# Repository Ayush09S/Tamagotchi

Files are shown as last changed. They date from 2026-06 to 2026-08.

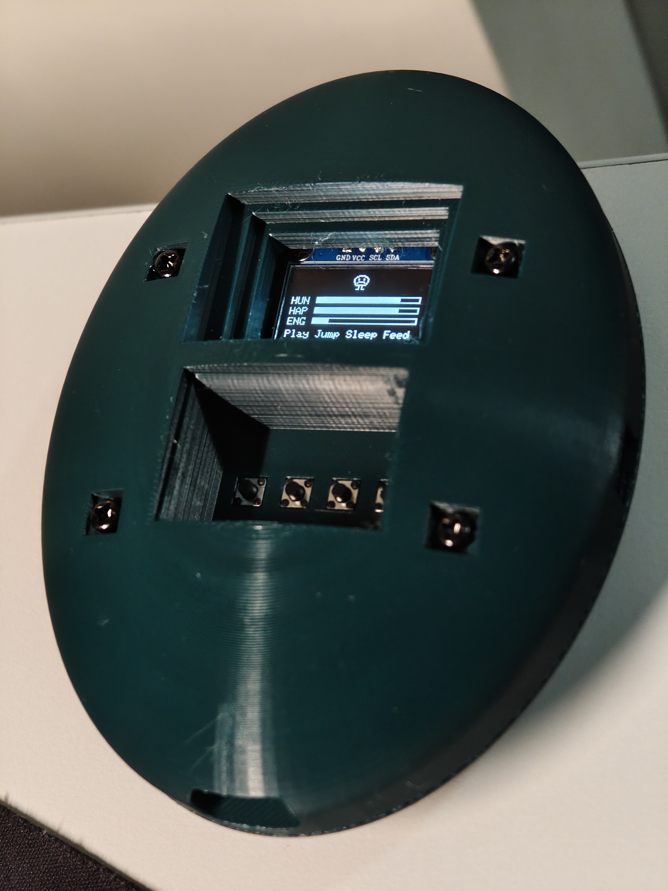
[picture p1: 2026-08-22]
Built_Images/Built_Tamagotchi.jpg

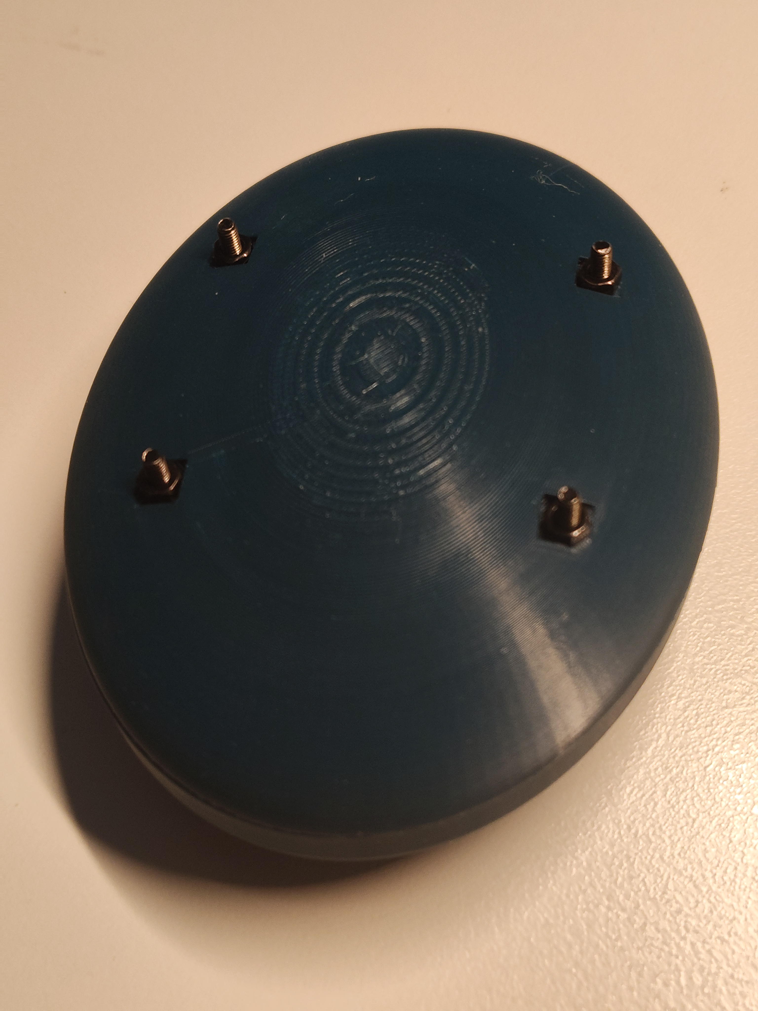
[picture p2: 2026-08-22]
Built_Images/Built_Tamagotchi_Bottom.jpg

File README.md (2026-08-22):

# Overview
A small digital pet as a physical device remake! It features four buttons and a buzzer. It also has an OLED display and can be recharged! The coding is made so that it can show it's emotions based on how it's treated. Whether it's not played with, not given sleep, it'll react. Make sure to keep it entertained! It also can be powered off into deep sleep in case you are busy and need to temporarily turn it off.

## Context
It was created as an entry to contribute to the Fallout Hackathon in Shenzhen run by Hack Club! It was quite involved, requiring the research of components, importing the EasyEda JLCPCB library of components library into Kicad, and properly understanding how to make a schematic and routing a PCB. I really liked the idea of a small, hand-held device that you can carry with you, and the idea of a tamagotchi is pretty sweet! It can also be used with both smaller LiPo batteries and medium sized ones too! It took 40+ hours to complete. I was really glad the coding was not crazy complicated!

## Zine
IRL_COMPLETE-Tamagotchi-Zine

# Specs
- 4 Push Buttons
- Latching Power Switch
- OLED screen

# How To Create
1. Create the PCB
  - Cut the PCB (with the Gerber file) through JLCPCB or a CNC machine and solder bought components needed (found in the BOM)
  - Use the provided files to solder header pins and components in the right places (Onshape link is a good one)

2. Print the models
  - Print the Casing, spacers and battery holder lid with the 3D Files provided on a 3D Printer (Note, the casing top, casing bottom, spacers and battery holder lid should all be printed seperately)
    OR
  - Buy the Casing printed from a printing service

3. Put it together
  - Put a bought or owned LiPo Battery and connect it to the bottom of the pcb, and place it into the allocated space in the casing
  - Use M3 Screws and nuts (buy or use owned ones) to screw the casing and PCB together

5. Program the PCB. (Sourced from [Tamagotchi Firmware Tutorial](https://fallout.hackclub.com/docs/guided-projects/tamagotchi-firmware#step-1-install-the-esp32-board-package))
  - Connect to the Tamagotchi's USB-C connector through a computer and apply the program provided through the Arduino IDE.
  - Make sure to downlooad to follow the steps below to get the correct libraries.
    
  - Open the Arduino IDE.
  - Go to File > Preferences (or Arduino IDE > Settings on macOS).
  - In the "Additional Boards Manager URLs" field, add the following URL: https://espressif.github.io/arduino-esp32/package_esp32_index.json > Note: If you already have URLs here, separate entries with commas.
  - Click OK to save the preferences.
  - Wait for the board index to download.

  - Open the Boards Manager by navigating to Tools > Board > Boards Manager.
  - In the search bar, type esp32.
  - Locate the entry for "esp32 by Espressif Systems".
  - Click the Install button. > Important: Ensure you are using version 3.0.0 or later, which supports the C6.
  - Wait for the installation to finish.

  - After installation, go to Tools > Board > esp32.
  - Select your board model: XIAO ESP32C6.

  - In Sketch > Include Library > Manage Libraries, install:
  -   Adafruit SSD1306 (by Adafruit)
  -   Adafruit GFX Library (by Adafruit), which will be prompted as a dependency.

  - Upload the code!

6. Done! Use the Tamagotchi as much as your heart desires!

# Full Design
Screenshot 2026-06-22 at 4 22 56 pm
Screenshot 2026-06-22 at 4 29 29 pm
Screenshot 2026-06-22 at 4 30 03 pm
Screenshot 2026-06-22 at 4 30 32 pm

# PCB
## Board
Screenshot 2026-06-22 at 5 34 54 am
Screenshot 2026-06-22 at 5 36 25 am

## Schematic
Screenshot 2026-06-22 at 5 36 53 am

# Casing
Onshape Link (Do not click, copy and paste it): https://cad.onshape.com/documents/55ba759bd32af63245a8fd64/w/0539768004f2bf5a541f17f4/e/c03fca18856a8a03d68f317d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
## Full
Screenshot 2026-06-22 at 6 36 05 am

## Top
Screenshot 2026-06-22 at 6 36 43 am
Screenshot 2026-06-22 at 6 37 21 am

## Bottom
Screenshot 2026-06-22 at 6 38 14 am
Screenshot 2026-06-22 at 6 38 38 am

## Built
Built_Tamagotchi
Built_Tamagotchi_Bottom

# BOM (AUD)
| No. | Item | Description | LCSC Supplier Number | Qty Req | Qty Must Buy | Unit Price | Total Price | Running Total | Link |
|:---|:---|:---|:---|:---|:---|:---|:---|:---|:---|
| 1 | 3D Print Filament | Elegoo PLA 1kg | | 1 | 1 | $19.95 | $19.95 | $19.95 | [Jaycar Link](https://www.jaycar.com.au/elegoo-pla-filament-brown-1-75mm-1kg/p/TL6415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) |
| | *Shipping* | Jaycar | | | | | $9.95 | $29.90 | |
| 2 | Screws | M3x30mm | | 4 | 10 | $0.13 | $1.33 | $31.23 | [Makerstore Link](https://www.makerstore.com.au/product/m3-button-head-screws-10-pack/?attribute_pa_length=30mm) |
| 3 | Nuts | M3 | | 4 | 4 | $0.14 | $0.56 | $31.79 | [Makerstore Link](https://www.makerstore.com.au/product/hard-m3nut-1/) |
| | *Shipping* | Makerstore | | | | | $7.50 | $39.29 | |
| 4 | Battery | LiPo Rechargeable 1100mAh | | 1 | 1 | $5.39 | $5.39 | $44.68 | [AliExpress Link](https://www.aliexpress.com/item/1005004824764461.html) |
| | *Shipping* | Aliexpress | | | | | $6.30 | $50.98 | |
| 5 | 7 Pin Headers | Male - 2.54mm Pitch | C6332200 | 2 | 20 | $0.04 | $0.72 | $51.70 | [LCSC Link](https://www.lcsc.com/product-detail/C6332200.html) |
| | 4 Pin Header | Male - 2.54mm Pitch | C5116483 | 1 | 20 | $0.03 | $0.64 | $52.34 | [LCSC Link](https://www.lcsc.com/product-detail/Pin-Headers_ZHOURI-2-54-1-4_C5116483.html) |
| 6 | Buzzer | BUZ-TH_BD12.5-P6.50-D1.4 | C49246964 | 1 | 10 | $0.08 | $0.82 | $53.16 | [LCSC Link](https://www.lcsc.com/product-detail/C49246964.html) |
| 7 | Push Buttons | SW-TH_4P-L4.5-W4.5-P3.00-LS4.8 | C2888493 | 4 | 50 | $0.02 | $0.75 | $53.91 | [LCSC Link](https://www.lcsc.com/product-image/C2888493.html) |
| 8 | Latching Button | SW-TH_TK-6580A-1 | C528770 | 1 | 1 | $0.31 | $0.31 | $54.22 | [LCSC Link](https://www.lcsc.com/product-detail/C528770.html) |
| 9 | OLED Screen | OLED-TH_L27.8-W27.2-P2.54_C9900033791 | C5248080 | 1 | 1 | $3.20 | $3.20 | $57.42 | [LCSC Link](https://www.lcsc.com/product-detail/C5248080.html) |
| | *Shipping* | LCSC | | | | | $9.10 | $66.52 | |
| | *Handling* | LCSC | | | | | $4.28 | $70.80 | |
| 10 | Microcontroller | XIAO-ESP32-C3-DIP-SMD | | 1 | 1 | $6.55 | $6.55 | $77.35 | [Seeed Studio Link](https://www.seeedstudio.com/Seeed-XIAO-ESP32C3-p-5431.html) |
| | *Shipping* | Seeed Studio | | | | | $7.05 | $84.40 | |
| 11 | PCB (without assembly) | Main board (Lead-Free Finish). Components to be soldered. | | 1 | 5 | $1.51 | $7.56 | $91.96 | [JLCPCB Link](https://jlcpcb.com/) |
| 11.2 | Additionals + Shipping | JLCPCB | | | | | $2.14 | $94.10 | |
| **-** | **Grand Total** | | | | | | | **$94.10** | |
# Additional Notes!
This was a Guided Project through Hack Club's Fallout's Docs. The github page of the tutorial is here https://github.com/TaniWanKenobi/tamagotchi. I really loved making it, and I really learnt a lot, just like with the USB Hub. If you are a beginner, I would suggest starting with a smaller project, but this project is INCREDIBLE as a second one! If you've got some experience programming, you'll definitely find this manageable to create.

WARNING - PRODUCTION FILES
The gerber is provided for the JLCPCB or any PCB cutting, but the BOM and CPL may not work properly when ordered, since the pins will not be assembled. This project is designed to have been soldered yourself, if you wish to alter it so that it can be ordered, you may do that but this project does not work in that way. YOU HAVE BEEN WARNED.

Sanity Checked by Kade Harrison and Revant Pandey

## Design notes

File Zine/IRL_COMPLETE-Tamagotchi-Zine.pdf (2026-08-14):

## By Ayush Singh, 16, Geelong Australia

# TAMAGOTCHI

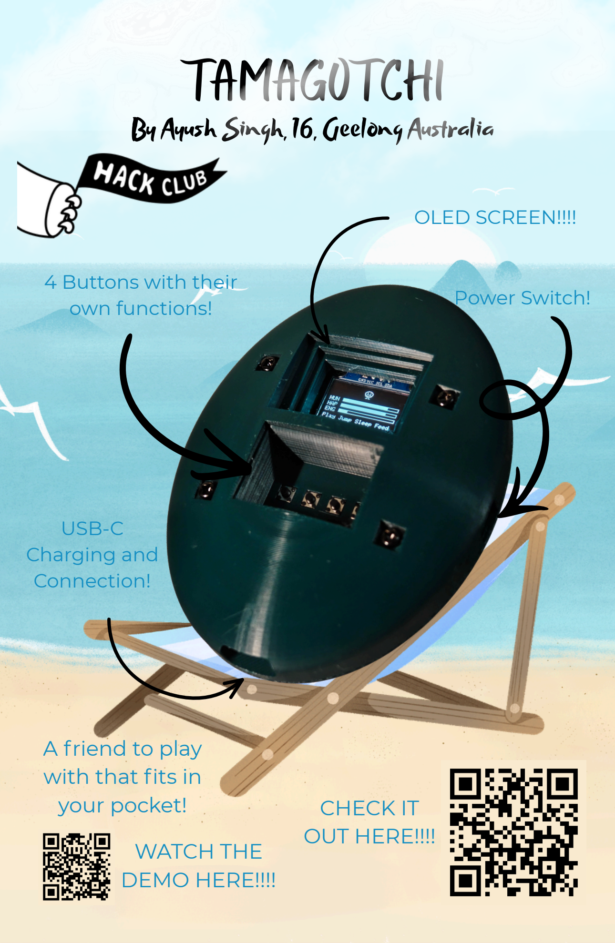
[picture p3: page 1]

OLED SCREEN!!!!

4 Buttons with their
own functions!

Power Switch!

USB-C
Charging and
Connection!

A friend to play
with that fits in
your pocket!
CHECK IT
OUT HERE!!!!
WATCH THE
DEMO HERE!!!!

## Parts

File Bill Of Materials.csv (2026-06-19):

No. | Item | Description | LCSC/JLCPCB Supplier Number (if applicable) | Qty | Unit Price | Total Price | Running Total | Link
1 | 3D Printer | Bambu X1C AVAILABLE AT SCHOOL |  | 1 | $1,099.00 | $1,099.00 | $1,099.00 | https://www.mobileciti.com.au/bambu-lab-x1-carbon-3d-printer-with-ams-refur-excellent?hsa_src=x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
2 | Screws | M3x30mm |  | 10 | $0.13 | $1.33 | $1,100.33 | https://www.makerstore.com.au/product/m3-button-head-screws-10-pack/?attribute_pa_length=30mm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
3 | Nuts | M3 |  | 4 | $0.14 | $0.56 | $1,100.89 | https://www.makerstore.com.au/product/hard-m3nut-1/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
4 | Battery | LiPo Rechargeable 1100mAh |  | 1 | $5.39 | $5.39 | $1,106.28 | https://www.aliexpress.com/item/1005004824764461.html?src=google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
5 | PCB (with assembly) | Main board that connects components and holds main chip |  | 1 | $23.59 | $23.59 | $1,129.87 | https://jlcpcb.com/
5.1 | Buzzer | BUZ-TH_BD12.5-P6.50-D1.4 | C49246964 | 1 | $0.01 | $0.01 | $1,129.87 | https://jlcpcb.com/partdetail/XHXDZ-1207_P65MM/C49246964
5.2 | Photo Resistor | RES-TH_L5.1-W4.3-P3.40-D0.5 | GL5528 | 1 | $0.07 | $0.07 | $1,129.87 | https://jlcpcb.com/partdetail/Senba_SensingTech-GL5528/C125627
5.3 | 10kΩ Resistor | RES-TH_BD2.7-L6.2-P10.20-D0.4 | C2903232 | 1 | $0.01 | $0.01 | $1,129.87 | https://jlcpcb.com/partdetail/VO-MF1_4W_10K_1_ST52/C2903232
5.4 | Push Buttons | SW-TH_4P-L4.5-W4.5-P3.00-LS4.8 | C2888493 | 4 | $0.01 | $0.04 | $1,129.87 | https://jlcpcb.com/partdetail/BZCN-TSC016A04518A/C2888493
5.5 | Latching Button | SW-TH_TK-6580A-1 | C528770 | 1 | $0.23 | $0.23 | $1,129.87 | https://jlcpcb.com/partdetail/Yuandi-TK_6580A1/C528770
5.6 | OLED Screen | OLED-TH_L27.8-W27.2-P2.54_C9900033791 | C5248080 | 1 | $2.27 | $2.27 | $1,129.87 | https://jlcpcb.com/partdetail/HS-HS96L03W2C03/C5248080
5.7 | Microcontroller | XIAO-ESP32-C3-DIP-SMD |  | 1 | $6.55 | $6.55 | $1,129.87 | https://www.seeedstudio.com/Seeed-XIAO-ESP32C3-p-5431.html

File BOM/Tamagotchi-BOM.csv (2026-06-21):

No. | Item | Description | LCSC Supplier Number (if applicable) | Qty Req | Qty Must Buy | Unit Price | Total Price | Running Total | Link
1 | 3D Print Filament | Elegoo PLA 1kg |  | 1 | 1 | $19.95 | $19.95 | $19.95 | https://www.jaycar.com.au/elegoo-pla-filament-brown-1-75mm-1kg/p/TL6415
 | Shipping | Jaycar |  |  |  |  | $9.95 | $29.90
2 | Screws | M3x30mm |  | 4 | 10 | $0.13 | $1.33 | $31.23 | https://www.makerstore.com.au/product/m3-button-head-screws-10-pack/?attribute_pa_length=30mm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
3 | Nuts | M3 |  | 4 | 4 | $0.14 | $0.56 | $31.79 | https://www.makerstore.com.au/product/hard-m3nut-1/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
 | Shipping | Makerstore |  |  |  |  | $7.50 | $39.29
4 | Battery | LiPo Rechargeable 1100mAh |  | 1 | 1 | $5.39 | $5.39 | $44.68 | https://www.aliexpress.com/item/1005004824764461.html?src=google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
 | Shipping | Aliexpress |  |  |  |  | $6.30 | $50.98
5 | 7 Pin Headers | Male - 2.54mm Pitch | C6332200 | 2 | 20 | $0.04 | $0.72 | $51.70 | https://www.lcsc.com/product-detail/C6332200.html
 | 4 Pin Header | Male - 2.54mm Pitch | C5116483 | 1 | 20 | $0.03 | $0.64 | $52.34 | https://www.lcsc.com/product-detail/Pin-Headers_ZHOURI-2-54-1-4_C5116483.html
6 | Buzzer | BUZ-TH_BD12.5-P6.50-D1.4 | C49246964 | 1 | 10 | $0.08 | $0.82 | $53.16 | https://www.lcsc.com/product-detail/C49246964.html
7 | Push Buttons | SW-TH_4P-L4.5-W4.5-P3.00-LS4.8 | C2888493 | 4 | 50 | $0.02 | $0.75 | $53.91 | https://www.lcsc.com/product-image/C2888493.html
8 | Latching Button | SW-TH_TK-6580A-1 | C528770 | 1 | 1 | $0.31 | $0.31 | $54.22 | https://www.lcsc.com/product-detail/C528770.html
9 | OLED Screen | OLED-TH_L27.8-W27.2-P2.54_C9900033791 | C5248080 | 1 | 1 | $3.20 | $3.20 | $57.42 | https://www.lcsc.com/product-detail/C5248080.html
 | Shipping | LCSC |  |  |  |  | $9.10 | $66.52
 | Handling | LCSC |  |  |  |  | $4.28 | $70.80
10 | Microcontroller | XIAO-ESP32-C3-DIP-SMD |  | 1 | 1 | $6.55 | $6.55 | $77.35 | https://www.seeedstudio.com/Seeed-XIAO-ESP32C3-p-5431.html
 | Shipping | Seeed Studio |  |  |  |  | $7.05 | $84.40
11 | PCB (without assembly) | Main board (Lead-Free Finish). Components to be soldered. |  | 1 | 5 | $1.51 | $7.56 | $91.96 | https://jlcpcb.com/
11.2 | Additionals + Shipping | JLCPCB |  |  |  |  | $2.14 | $94.10
 | Grand Total |  |  |  |  |  |  | $94.10

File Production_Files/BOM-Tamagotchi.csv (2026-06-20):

Comment | Designator | Footprint | LCSC | Quantity
1207-P6.5MM | BUZZER1 | BUZ-TH_BD12.5-P6.50-D1.4 | C49246964 | 1
HS96L03W2C03 | U2 | OLED-TH_L27.8-W27.2-P2.54_C9900033791 | C5248080 | 1
TK-6580A-1 | SW5 | SW-TH_TK-6580A-1 | C528770 | 1
TSC016A04518A | SW1,SW2,SW3,SW4 | SW-TH_4P-L4.5-W4.5-P3.00-LS4.8 | C2888493 | 4
XIAO-ESP32-C3-DIP-SMD | U1 | XIAO-ESP32-C3-DIP-SMD |  | 1
Battery_Cell | BT1 | PinHeader_1x02_P2.54mm_Vertical |  | 1

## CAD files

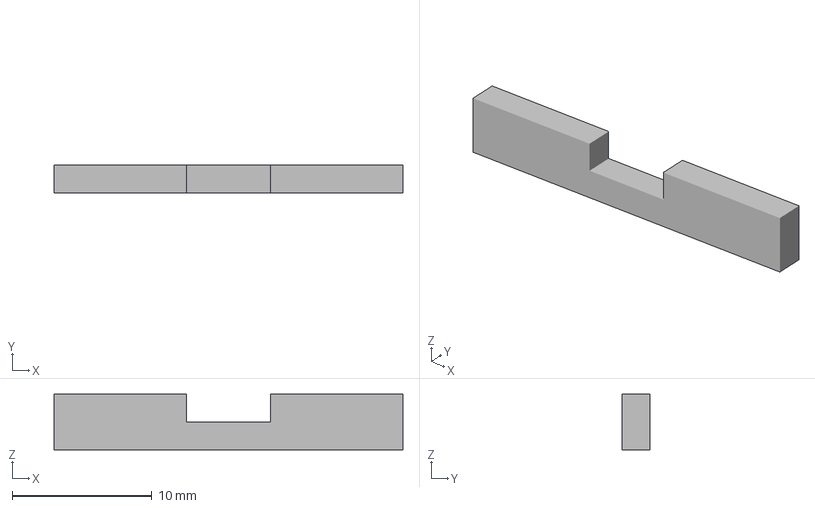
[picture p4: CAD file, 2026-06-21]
CAD/Spacers/Tamagotchi-Spacer_3_Part.step
25.0 x 2.00 x 4.00 mm

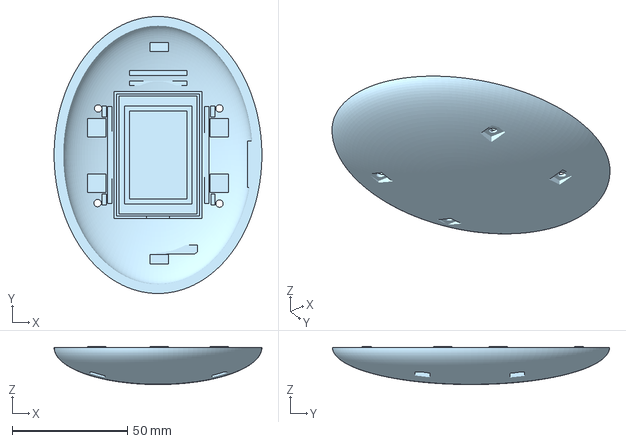
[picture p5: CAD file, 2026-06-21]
CAD/Tamagotchi-Bottom.step
90.0 x 120.0 x 16.5 mm

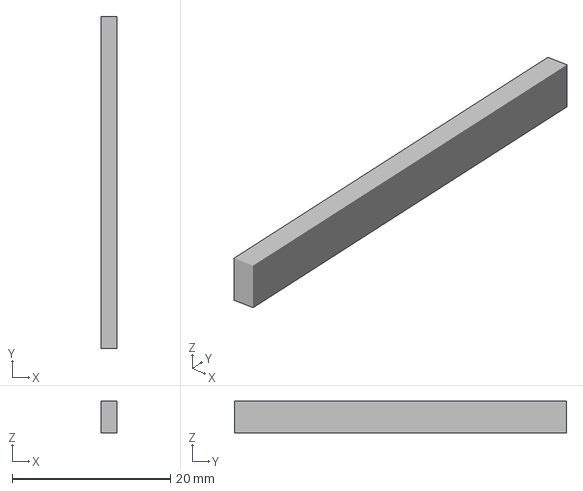
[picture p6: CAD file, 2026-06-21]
CAD/Spacers/Tamagotchi-Spacer_2_Part.step
2.00 x 42.0 x 4.00 mm

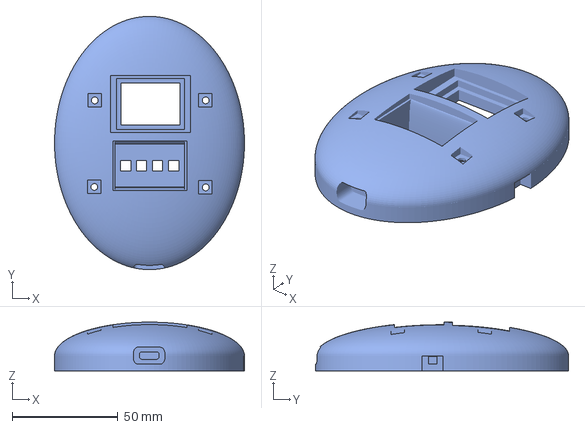
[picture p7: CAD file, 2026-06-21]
CAD/Tamagotchi-Top.step
90.0 x 120.0 x 23.1 mm

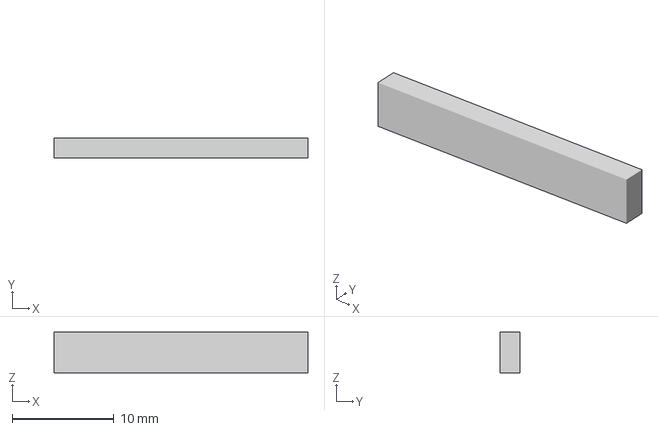
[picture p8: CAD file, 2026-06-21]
CAD/Spacers/Tamagotchi-Spacer_4_Part.step
25.0 x 2.00 x 4.00 mm

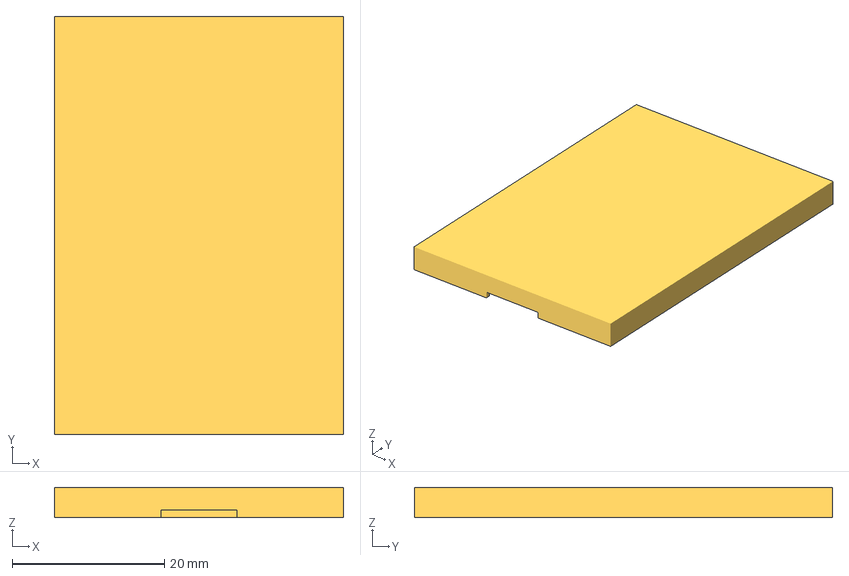
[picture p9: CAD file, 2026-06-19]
CAD/Tamagotchi-Battery_Lid.step
38.0 x 55.0 x 4.00 mm

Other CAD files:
CAD/Spacers/Tamagotchi-Spacer_1_Part.step

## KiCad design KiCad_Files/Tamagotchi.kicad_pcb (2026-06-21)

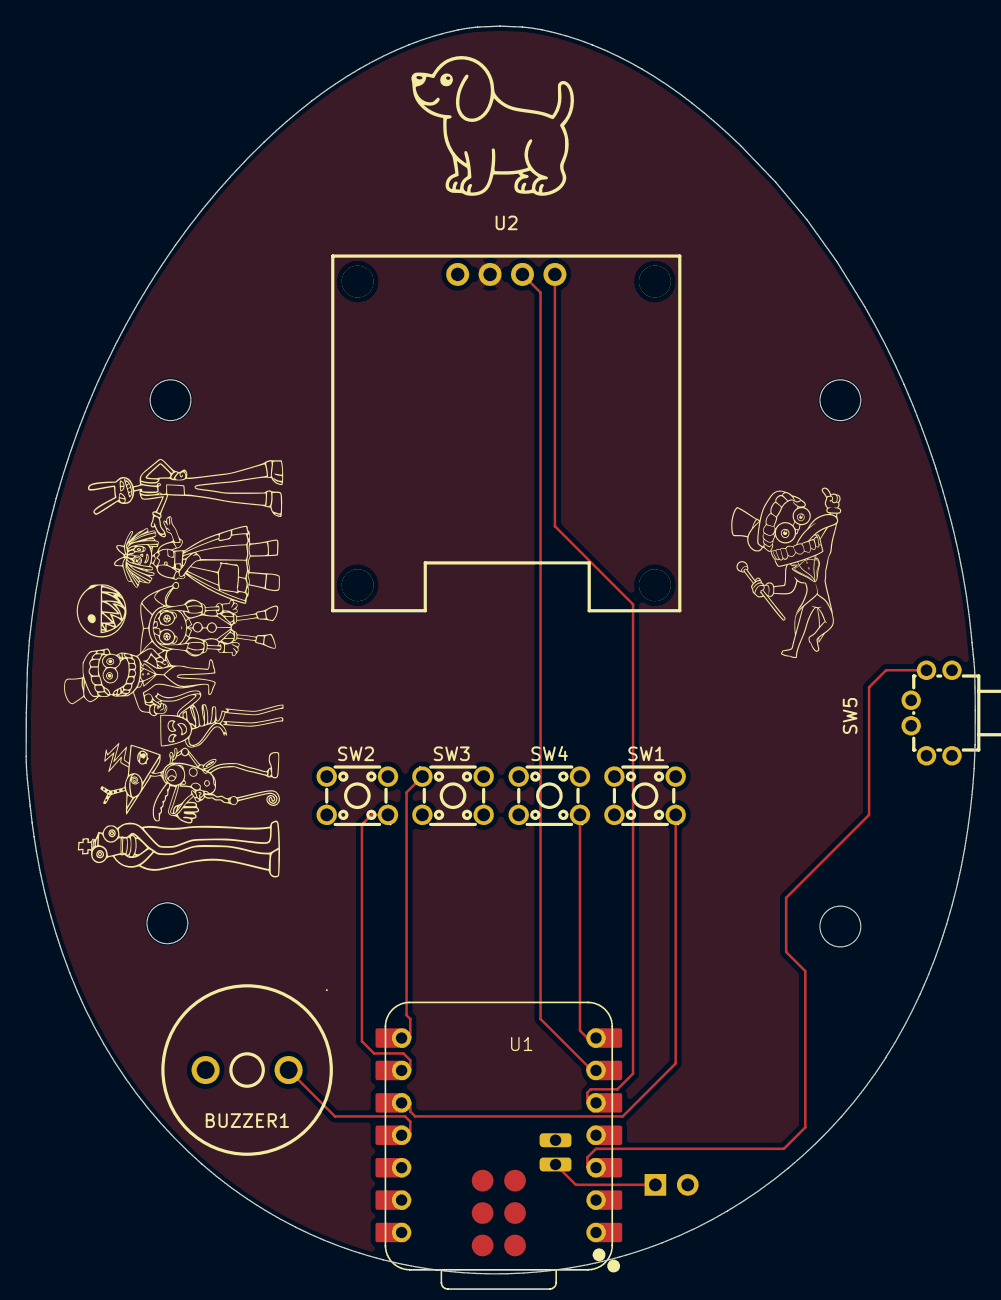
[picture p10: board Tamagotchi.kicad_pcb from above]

Board: 2 copper layers, 74.4 x 97.8 mm, 9 parts (1 on the bottom side), 11 nets.

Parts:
BT1: Battery_Cell; PinHeader_1x02_P2.54mm_Vertical
BUZZER1: 1207-P6.5MM; BUZ-TH_BD12.5-P6.50-D1.4
SW1, SW2, SW3, SW4: TSC016A04518A; SW-TH_4P-L4.5-W4.5-P3.00-LS4.8
SW5: TK-6580A-1; SW-TH_TK-6580A-1
U1: XIAO-ESP32-C3-DIP-SMD
U2: HS96L03W2C03; OLED-TH_L27.8-W27.2-P2.54_C9900033791

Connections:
+3V3: U1.12 (3V3), U2.2 (VCC)
+BATT: BT1.1 (+), U1.22
GND: BT1.2 (-), BUZZER1.2 (-), SW1.4, SW2.4, SW3.4, SW4.4, SW5.3, U1.13 (GND), U1.21, U2.1 (GND)
unnamed: BUZZER1.1 (+), U1.11 (GPIO10_D10_MOSI)
unnamed: SW5.2, U1.3 (GPIO4_A2_D2)
unnamed: U1.5 (GPIO6_D4_SDA), U2.4 (SDA)
unnamed: U1.6 (GPIO7_D5_SCL), U2.3 (SCL)
unnamed: SW2.1, U1.9 (GPIO8_D8_SCK)
unnamed: SW1.1, U1.10 (GPIO9_D9_MISO)
unnamed: SW3.1, U1.8 (GPIO20_D7_RX)
unnamed: SW4.1, U1.7 (GPIO21_D6_TX)

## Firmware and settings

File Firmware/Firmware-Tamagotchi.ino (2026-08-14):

#include <Wire.h>
#include <Adafruit_GFX.h>
#include <Adafruit_SSD1306.h>

// --- Pin Definitions ---
// Buttons
#define Btn_Left 9        // SW1 -> GPIO9
#define Btn_Mid_Left 8    // SW2 -> GPIO8
#define Btn_Mid_Right 20  // SW3 -> GPIO20
#define Btn_Right 21      // SW4 -> GPIO21

// Power Button (Momentary)
#define Power_Btn 4  // SW5 -> GPIO4

// I2C OLED
#define SdaPin 6  // OLED SDA -> GPIO6
#define SclPin 7  // OLED SCL -> GPIO7

// Buzzer
#define Buzzer_Pin 10  // Buzzer signal -> GPIO10

// --- Display Setup ---
#define SCREEN_WIDTH 128
#define SCREEN_HEIGHT 64
#define OLED_RESET -1

Adafruit_SSD1306 display(SCREEN_WIDTH, SCREEN_HEIGHT, &Wire, OLED_RESET);

// --- Pet Logic ---
struct Pet {
  int hunger;         // 0 to 100 (0 = starving, 100 = full)
  int happiness;      // 0 to 100 (0 = miserable, 100 = ecstatic)
  int energy;         // 0 to 100 (0 = exhausted, 100 = fully rested)
  unsigned long age;  // total seconds the pet has been alive
};

Pet pet;

enum Screen {
  SCREEN_MAIN,
  SCREEN_FEED,
  SCREEN_PLAY,
  SCREEN_SLEEP,
  SCREEN_JUMP
};

Screen currentScreen = SCREEN_MAIN;

unsigned long screenEnteredAt = 0;
bool actionApplied = false;
unsigned long lastUpdate = 0;

// Level GPIO4 reads when the switch is in the OFF position.
// Flip this to HIGH if it's backwards on your board.
#define POWER_OFF_LEVEL LOW

void checkPowerButton() {
  if (digitalRead(Power_Btn) != POWER_OFF_LEVEL) return;  // switch is ON, carry on

  delay(50);
  if (digitalRead(Power_Btn) != POWER_OFF_LEVEL) return;  // bounce, ignore

  display.clearDisplay();
  display.display();
  display.ssd1306_command(SSD1306_DISPLAYOFF);

  // Wake on the opposite level to the one we're sleeping at
  gpio_wakeup_enable(GPIO_NUM_4,
    POWER_OFF_LEVEL == LOW ? GPIO_INTR_HIGH_LEVEL : GPIO_INTR_LOW_LEVEL);
  esp_sleep_enable_gpio_wakeup();
  esp_light_sleep_start();

  // --- resumes here when the switch is flipped back ON ---
  delay(50);
  display.ssd1306_command(SSD1306_DISPLAYON);
  lastUpdate = millis();
}

void setup() {
  Serial.begin(115200);

  pinMode(Btn_Left, INPUT_PULLUP);
  pinMode(Btn_Mid_Left, INPUT_PULLUP);
  pinMode(Btn_Mid_Right, INPUT_PULLUP);
  pinMode(Btn_Right, INPUT_PULLUP);
  pinMode(Buzzer_Pin, OUTPUT);
  pinMode(Power_Btn, INPUT_PULLUP);

  // Initialize I2C with the specific pins for the schematic
  Wire.begin(SdaPin, SclPin);

  display.begin(SSD1306_SWITCHCAPVCC, 0x3C);
  display.clearDisplay();
  display.setTextSize(1);
  display.setTextColor(SSD1306_WHITE);
  display.setCursor(0, 0);

  display.println("Tamagotchi says...");
  display.display();
  delay(1000);

  display.println("Hello World!");
  display.display();
  delay(1000);

  pet.hunger = 80;
  pet.happiness = 80;
  pet.energy = 80;
  pet.age = 0;
}


void updatePet() {
  if (millis() - lastUpdate > 5000) {  // every 5 seconds
    pet.hunger--;
    pet.happiness--;
    pet.energy--;

    if (pet.hunger < 0) pet.hunger = 0;
    if (pet.happiness < 0) pet.happiness = 0;
    if (pet.energy < 0) pet.energy = 0;

    pet.age += 5;
    lastUpdate = millis();
  }
}

unsigned long lastButtonPress = 0;

void checkButtons() {
  if (millis() - lastButtonPress < 200) return;  // debounce: ignore presses within 200ms

  if (digitalRead(Btn_Left) == LOW) {
    currentScreen = SCREEN_FEED;
    tone(Buzzer_Pin, 1000, 50);
    lastButtonPress = millis();
    screenEnteredAt = millis();
    actionApplied = false;
  } else if (digitalRead(Btn_Mid_Left) == LOW) {
    currentScreen = SCREEN_PLAY;
    tone(Buzzer_Pin, 1200, 50);
    lastButtonPress = millis();
    screenEnteredAt = millis();
    actionApplied = false;
  } else if (digitalRead(Btn_Mid_Right) == LOW) {
    currentScreen = SCREEN_JUMP;
    tone(Buzzer_Pin, 1200, 50);
    lastButtonPress = millis();
    screenEnteredAt = millis();
    actionApplied = false;
  } else if (digitalRead(Btn_Right) == LOW) {
    currentScreen = SCREEN_SLEEP;
    tone(Buzzer_Pin, 800, 50);
    lastButtonPress = millis();
    screenEnteredAt = millis();
    actionApplied = false;
  }
}

void handleScreenLogic() {
  if (actionApplied) {
      if (millis() - screenEnteredAt > 800){
        currentScreen = SCREEN_MAIN;
      }
      return;
  }

  switch (currentScreen) {

    case SCREEN_FEED:
      pet.hunger += 10;
      if (pet.hunger > 100) pet.hunger = 100;
      break;

    case SCREEN_PLAY:
      pet.happiness += 10;
      pet.energy -= 5;
      if (pet.happiness > 100) pet.happiness = 100;
      if (pet.energy < 0) pet.energy = 0;
      break;

    case SCREEN_JUMP:
      pet.happiness += 20;
      pet.energy -= 10;
      if (pet.happiness > 100) pet.happiness = 100;
      if (pet.energy < 0) pet.energy = 0;
      break;

    case SCREEN_SLEEP:
      pet.energy += 15;
      if (pet.energy > 100) pet.energy = 100;
      break;

    case SCREEN_MAIN:
      break;  // do nothing, just display stats
  }

  actionApplied = true;
}

// Stat Happy (Happiness > 40)
const unsigned char PROGMEM petHappy[] = {
  0b00000000, 0b00000000,
  0b00000111, 0b11100000,
  0b00011000, 0b00011000,
  0b00100000, 0b00000100,
  0b01000100, 0b00100010,
  0b01000000, 0b00000010,
  0b01010000, 0b00001010,
  0b01001000, 0b00010010,
  0b00100111, 0b11100100,
  0b00100000, 0b00000100,
  0b00011111, 0b11111000,
  0b00000010, 0b01000000,
  0b00000010, 0b01000000,
  0b00000010, 0b01000000,
  0b00001110, 0b01110000,
  0b00000000, 0b00000000
};

// Stat Jump
const unsigned char PROGMEM petJump[] = {
  0b00000000, 0b00000000,
  0b00000111, 0b11100000,
  0b00011000, 0b00011000,
  0b00100000, 0b00000100,
  0b01000100, 0b00100010,
  0b01000000, 0b00000010,
  0b01010000, 0b00001010,
  0b01001000, 0b00010010,
  0b00100111, 0b11100100,
  0b00100000, 0b00000100,
  0b00011111, 0b11111000,
  0b00000010, 0b01000000,
  0b00001110, 0b01110000,
  0b00000000, 0b00000000,
  0b00000000, 0b00000000,
  0b00000000, 0b00000000
};

// Stat Sad (Happiness <= 40)
const unsigned char PROGMEM petSad[] = {
  0b00000000, 0b00000000,
  0b00000111, 0b11100000,
  0b00011000, 0b00011000,
  0b00100000, 0b00000100,
  0b01000100, 0b00100010,
  0b01000100, 0b00100010,
  0b01000000, 0b00000010,
  0b01000111, 0b11100010,
  0b00101000, 0b00010100,
  0b00100000, 0b00000100,
  0b00011111, 0b11111000,
  0b00000010, 0b01000000,
  0b00000010, 0b01000000,
  0b00000010, 0b01000000,
  0b00001110, 0b01110000,
  0b00000000, 0b00000000
};

// Stat Neutral
const unsigned char PROGMEM petNeutral[] = {
  0b00000000, 0b00000000,
  0b00000111, 0b11100000,
  0b00011000, 0b00011000,
  0b00100000, 0b00000100,
  0b01000100, 0b00100010,
  0b01000000, 0b00000010,
  0b01000000, 0b00000010,
  0b01001000, 0b00010010,
  0b00100111, 0b11100100,
  0b00100000, 0b00000100,
  0b00011111, 0b11111000,
  0b00000010, 0b01000000,
  0b00000010, 0b01000000,
  0b00000010, 0b01000000,
  0b00001110, 0b01110000,
  0b00000000, 0b00000000
};

// Stat Sleeping
const unsigned char PROGMEM petSleep[] = {
  0b00000000, 0b00000000,
  0b00000111, 0b11100000,
  0b00011000, 0b00011000,
  0b00100000, 0b00000100,
  0b01000100, 0b00100010,
  0b01001110, 0b01110010,
  0b01000100, 0b00100010,
  0b01000000, 0b00000010,
  0b00100111, 0b11100100,
  0b00100000, 0b00000100,
  0b00011111, 0b11111000,
  0b00000010, 0b01000000,
  0b00000010, 0b01000000,
  0b00000010, 0b01000000,
  0b00001110, 0b01110000,
  0b00000000, 0b00000000
};

// Stat Sleeping
const unsigned char PROGMEM petTired[] = {
  0b00000000, 0b00000000,
  0b00000111, 0b11100000,
  0b00011000, 0b00011000,
  0b00100000, 0b00000100,
  0b01000100, 0b00100010,
  0b01001010, 0b01010010,
  0b01000100, 0b00100010,
  0b01000000, 0b00000010,
  0b00100111, 0b11100100,
  0b00100000, 0b00000100,
  0b00011111, 0b11111000,
  0b00000010, 0b01000000,
  0b00000010, 0b01000000,
  0b00000010, 0b01000000,
  0b00001110, 0b01110000,
  0b00000000, 0b00000000
};

const unsigned char PROGMEM petHungry[] = {
  0b00000000, 0b00000000,
  0b00000111, 0b11100000,
  0b00011000, 0b00011000,
  0b00100000, 0b00000100,
  0b01000100, 0b00100010,
  0b01000000, 0b00000010,
  0b01011111, 0b11111010,
  0b01000000, 0b11100010,
  0b00100000, 0b11000100,
  0b00100000, 0b00000100,
  0b00011111, 0b11111000,
  0b00000010, 0b01000000,
  0b00000010, 0b01000000,
  0b00000010, 0b01000000,
  0b00001110, 0b01110000,
  0b00000000, 0b00000000
};

void render() {
  display.clearDisplay();

  // Choose the right sprite based on pet stats
  const unsigned char* sprite;
  if (currentScreen == SCREEN_JUMP)
  {
    sprite = petJump;
  } 
  else if (currentScreen == SCREEN_SLEEP)
  {
    sprite = petSleep;
  }
  else if (pet.happiness < 30 || pet.energy < 30)
  {
    sprite = petSad;
  } 
  else if (pet.hunger > 50 && pet.happiness > 50 && pet.energy > 50) 
  {
    sprite = petHappy;
  } 
  else if (pet.hunger < 30) 
  {
    sprite = petHungry;
  } 
  else 
  {
    sprite = petNeutral;
  }

  // Draw the pet sprite (centered horizontally, near the top)
  display.drawBitmap(56, 2, sprite, 16, 16, SSD1306_WHITE);

  // Draw stat bars below the pet
  display.setTextSize(1);

  display.setCursor(0, 24);
  display.print("HUN ");
  drawBar(24, 24, pet.hunger);

  display.setCursor(0, 34);
  display.print("HAP ");
  drawBar(24, 34, pet.happiness);

  display.setCursor(0, 44);
  display.print("ENG ");
  drawBar(24, 44, pet.energy);

  // Button labels at the bottom
  display.setCursor(0, 56);
  display.println("Play Jump Sleep Feed");

  display.display();
}

// Draws a stat bar: empty rectangle with a filled portion based on value (0 to 100)
void drawBar(int x, int y, int value) {
  int barWidth = 100;
  int barHeight = 6;
  int fillWidth = map(value, 0, 100, 0, barWidth);

  display.drawRect(x, y, barWidth, barHeight, SSD1306_WHITE);   // outline
  display.fillRect(x, y, fillWidth, barHeight, SSD1306_WHITE);  // filled portion
}

void loop() {
  checkPowerButton();   // 1. Check for momentary sleep press
  checkButtons();       // 2. Read input
  updatePet();          // 3. Update state over time
  handleScreenLogic();  // 4. Process actions
  render();             // 5. Display results
  delay(100);           // 6. Short pause
}

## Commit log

2026-06-14 Add PCB images to README
    Added PCB images to the README for visual reference.
2026-06-14 KiCad Source File import
    [Tamagotchi.kicad_pcb, Tamagotchi.kicad_sch]
2026-06-17 Update README with detailed creation instructions
    Expanded the README with detailed instructions on creating the Tamagotchi device, including PCB creation, casing, assembly, and programming.
2026-06-19 KiCad Source Files Upload
    [Tamagotchi.kicad_pcb, Tamagotchi.kicad_sch]
2026-06-19 Rename Tamagotchi.kicad_pcb to KiCad Files/Tamagotchi.kicad_pcb
    [Tamagotchi.kicad_pcb]
2026-06-19 Rename Tamagotchi.kicad_pro to Kicad Files/Tamagotchi.kicad_pro
2026-06-19 Source files reuploaded
    [Tamagotchi.kicad_sch]
2026-06-19 Gerber Upload
2026-06-19 Rename BOM-Tamagotchi.csv to Production Files/BOM-Tamagotchi.csv
    [BOM-Tamagotchi.csv]
2026-06-19 BOM Upload
    [Bill Of Materials.csv]
2026-06-19 Rename Bill Of Materials.csv to BOM/Bill Of Materials.csv
    [Bill Of Materials.csv]
2026-06-19 Add BOM section with item descriptions and links
    Added a Bill of Materials (BOM) section with item details.
2026-06-20 Add placeholder file in KiCad Files directory
2026-06-20 Revise BOM formatting and section details
    Updated the BOM section and fixed formatting issues in the README.
2026-06-20 Add new PCB images to README
2026-06-20 Fix unit price and total for PCB in BOM
    Updated unit price for PCB and total price calculations.
    [Tamagotchi - BOM.csv]
2026-06-20 Update Tamagotchi - BOM.csv
    [Tamagotchi - BOM.csv]
2026-06-20 Source File Upload
    [Tamagotchi.kicad_pcb, Tamagotchi.kicad_sch]
2026-06-21 Revise README with updated assembly instructions and BOM
    Updated instructions for PCB creation and assembly, clarified components needed, and revised BOM format with shipping costs.
2026-06-22 Update README with design and PCB images
    Added design images and PCB details to the README.
